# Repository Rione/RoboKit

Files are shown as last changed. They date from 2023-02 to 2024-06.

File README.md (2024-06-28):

# RoboKit 環境構築

<aside>
👉 目標：自分のPCにRoboKit用のプログラムを持ってきて、VSCodeに拡張機能のPlatformIOをinstallする。

</aside>

# 自分のPCにRoboKitのプログラムを持ってくる

↓これを開く

[GitHub - Rione/RoboKit](https://github.com/Rione/RoboKit/tree/master)

## 2つの方法がある

- ファイルをダウンロードする
- ファイル(リポジトリ)をクローンする

## 方法1

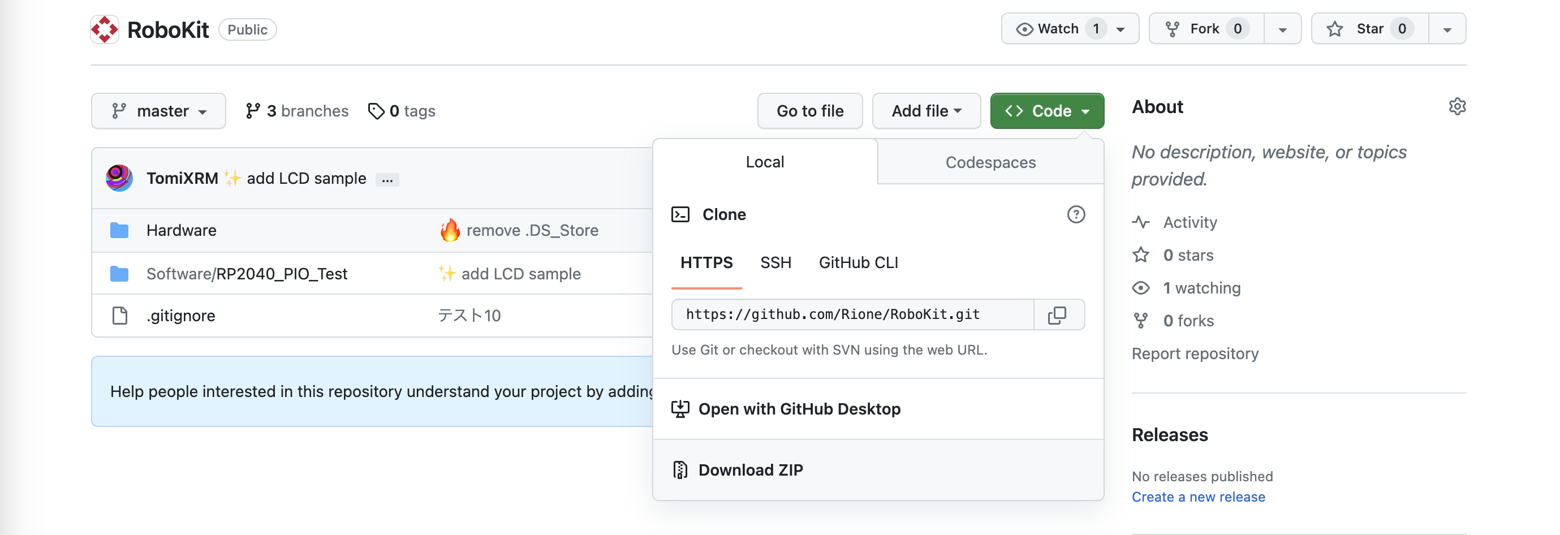
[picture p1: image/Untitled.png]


`<>Code`から、`Download ZIP`でZIPファイルをダウンロード。→ 展開する。

RoboKit-masterというフォルダがDownloadsフォルダに保存されている

## 方法2



今回はDownloadsフォルダにRoboKitのフォルダを複製する
↓一行ずつターミナルで実行

```bash
cd
cd Downloads
git clone https://github.com/Rione/RoboKit.git
```

※ ちなみに…  `git clone (URL)` で既存のリポジトリを自分のPC内に複製できる

RoboKitというフォルダがDownloadsフォルダに保存されている

# VSCodeのインストール

[](https://code.visualstudio.com/)

# VSCodeにPlatform IOをinstallする

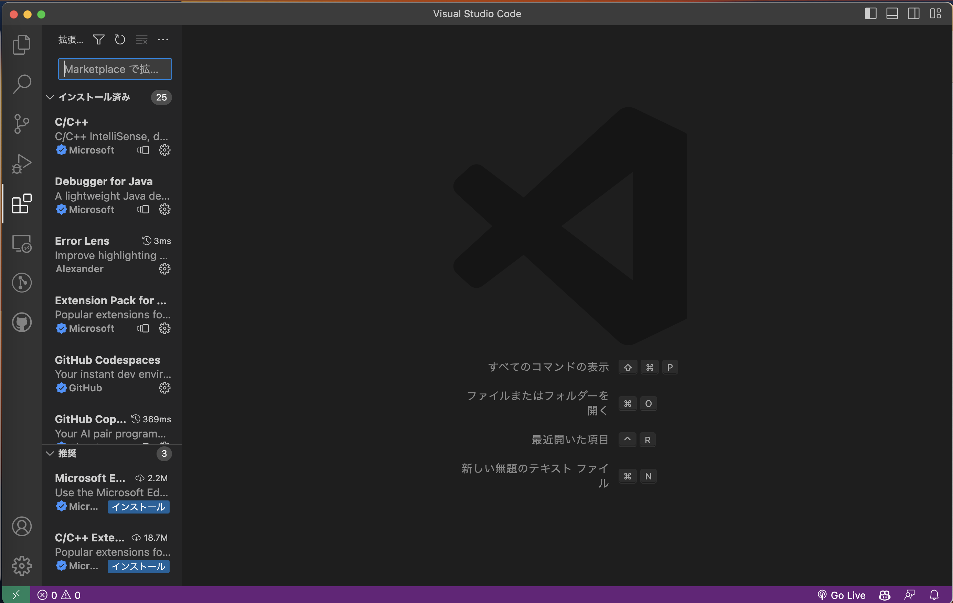
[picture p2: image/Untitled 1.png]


サイドバーの拡張機能（ブロックのようなアイコン）をクリック

上の検索バーにPlatform IOと入力

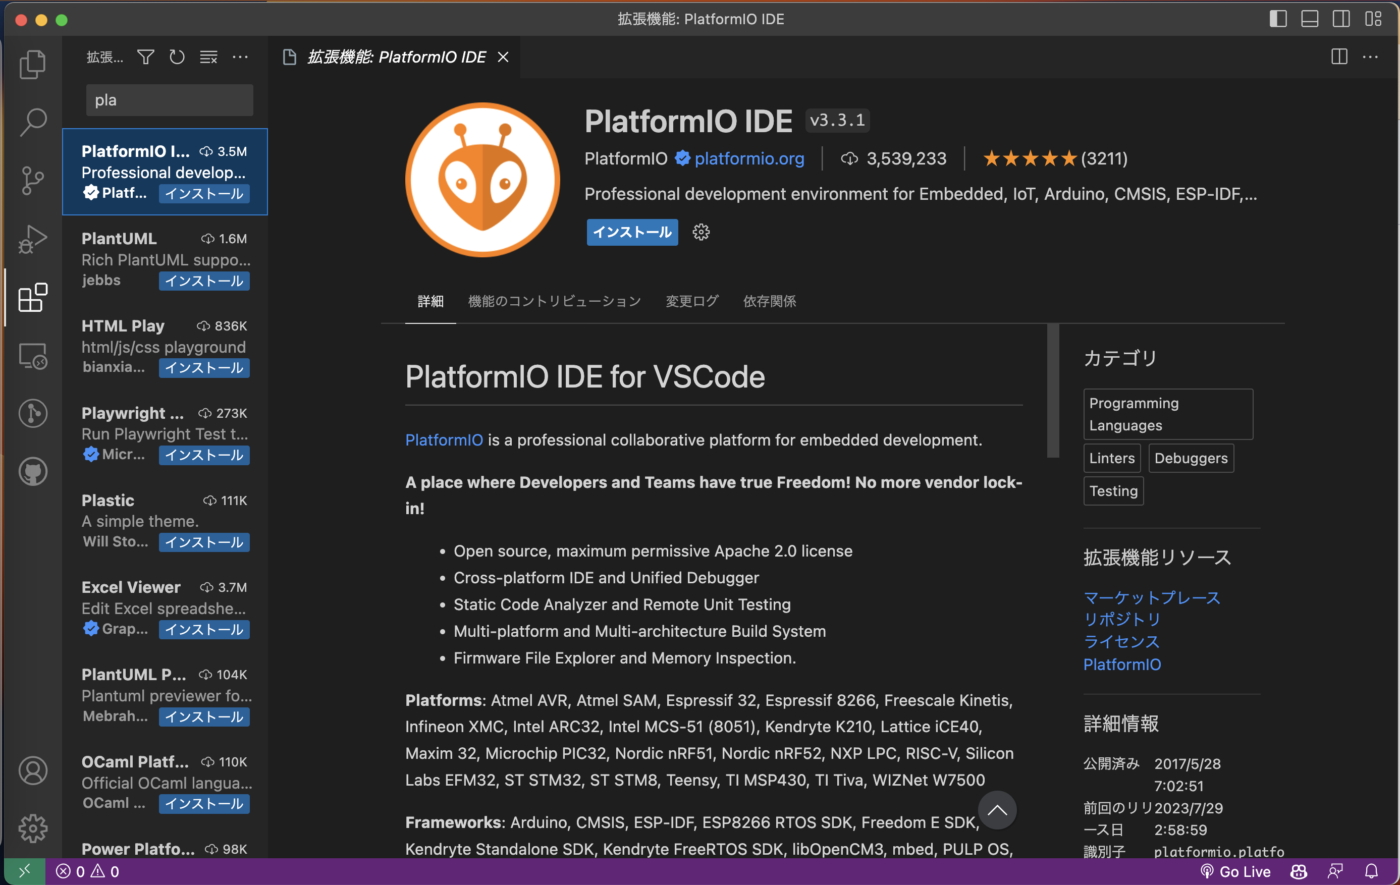
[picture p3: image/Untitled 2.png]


これをinstall(インストールボタンをクリックすることで入ります)

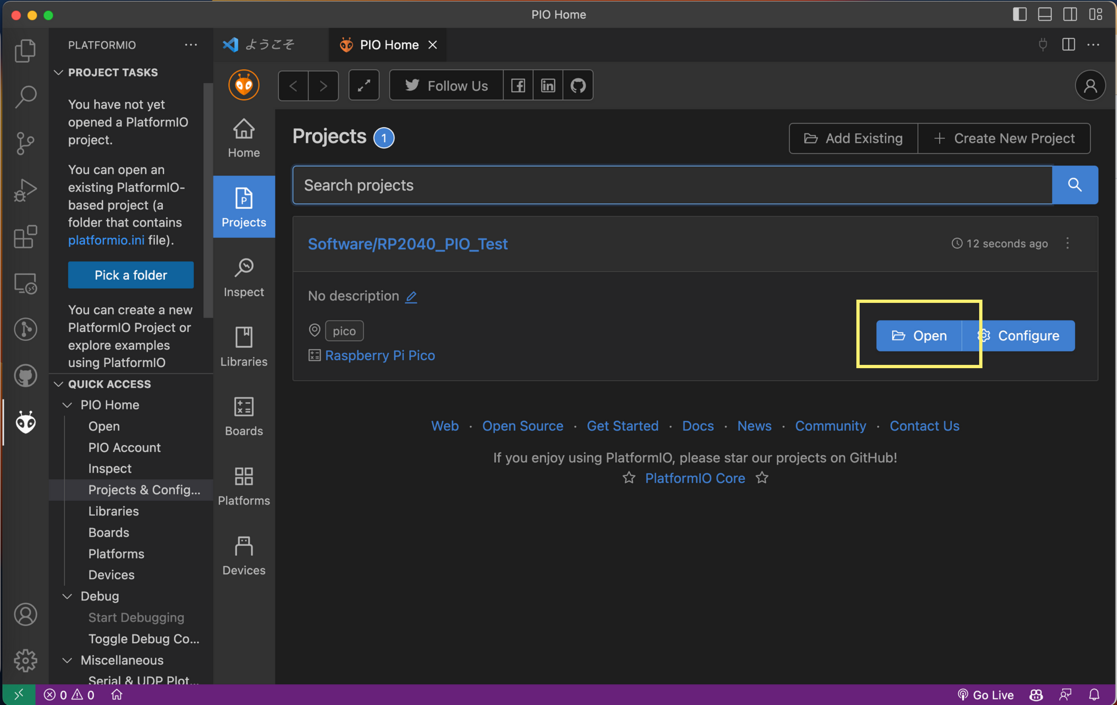
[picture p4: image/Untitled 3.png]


サイドバーからPlatform IOを選択して、Quick Access > PIO Home > Projects & Configure を選択すると、上の画面が出てくる。

画面右側のOpenを押すと、RoboKitのテスト用フォルダが開かれる

---

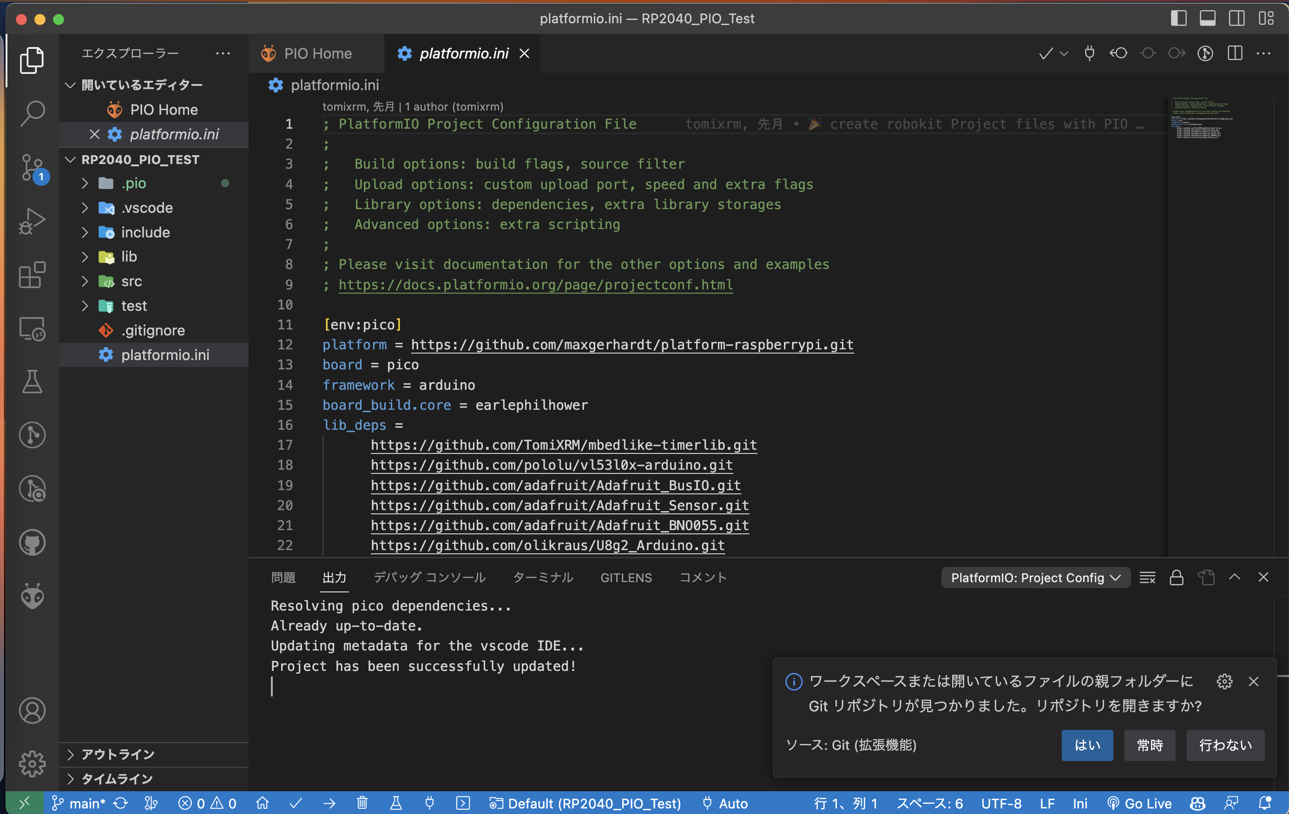
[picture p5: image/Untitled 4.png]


「出力」でいろいろ流れて、最終的に上の画面になったら成功！

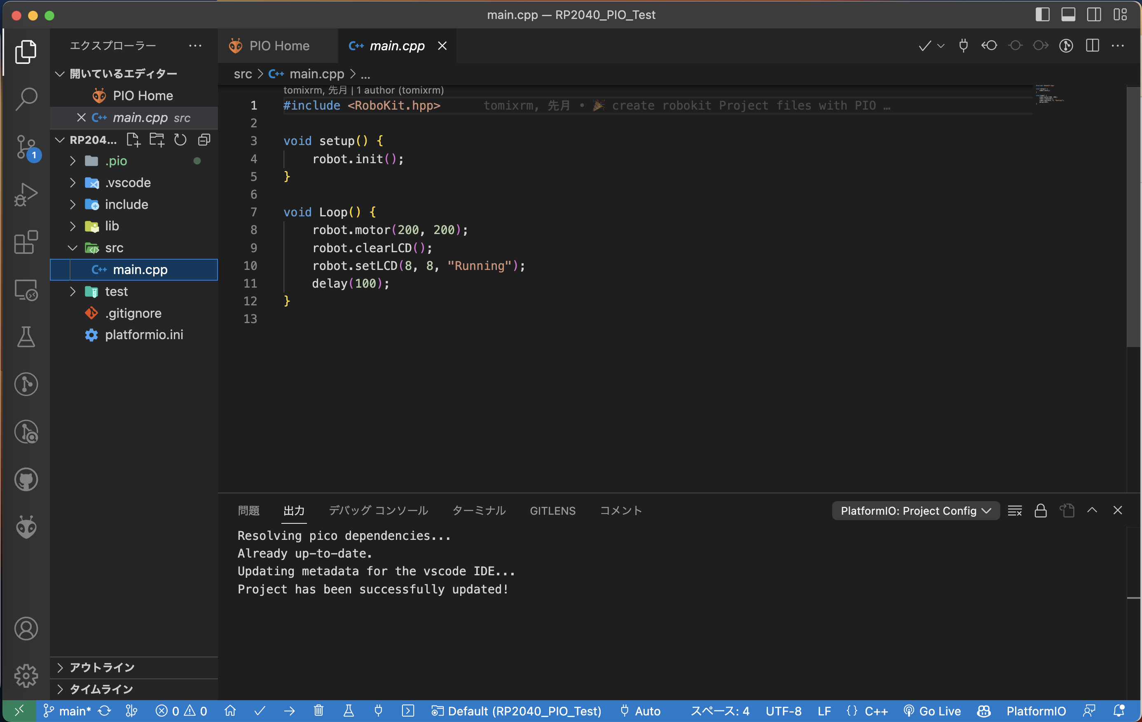
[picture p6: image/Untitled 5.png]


企画で使用するファイルは上画面で表示されている、main.cppだけです。

余力のある人は、実際にビルドができるか確認してもらえると嬉しいです。
下の青いラインに並んでいる、✅を押すとビルド、→を押すと書き込みができます。

以上でPCの事前準備はおしまいですが、分からないことがあれば遠慮せずに聞いてください！

---

# Windowsの諸注意

WindowsにGitが入っている必要があります．Gitのインストールをしてください．(自分で調べてください)

### Gitが入っているかの確認

ターミナルで次のコマンドを打ってみてください．

```
git help
```

と打って反応があればGitが入っている証拠です．

- ターミナルで期待される反応はこんな感じです．
    
    ```
    git help
    usage: git [--version] [--help] [-C <path>] [-c <name>=<value>]
               [--exec-path[=<path>]] [--html-path] [--man-path] [--info-path]
               [-p | --paginate | -P | --no-pager] [--no-replace-objects] [--bare]
               [--git-dir=<path>] [--work-tree=<path>] [--namespace=<name>]
               [--super-prefix=<path>] [--config-env=<name>=<envvar>]
               <command> [<args>]
    
    These are common Git commands used in various situations:
    
    start a working area (see also: git help tutorial)
       clone     Clone a repository into a new directory
       init      Create an empty Git repository or reinitialize an existing one
    
    work on the current change (see also: git he
    ```

### RoboKitのファイルの初期化時にエラーが出る(longpathエラー)

- WindowsのgitはMacと違い，longpath = falseになっているので，trueにしましょう
- WindowsのGitの入っているPCで以下のコマンドを実行してください．

```
git config --system core.longpaths true
```

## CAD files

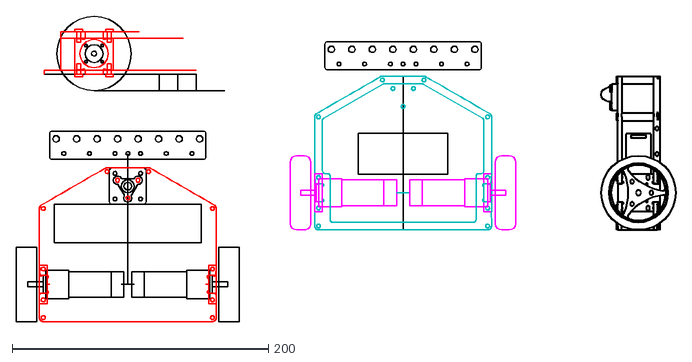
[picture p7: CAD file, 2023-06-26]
Hardware/mechanical_design/robot..dxf
514.6 x 238.2

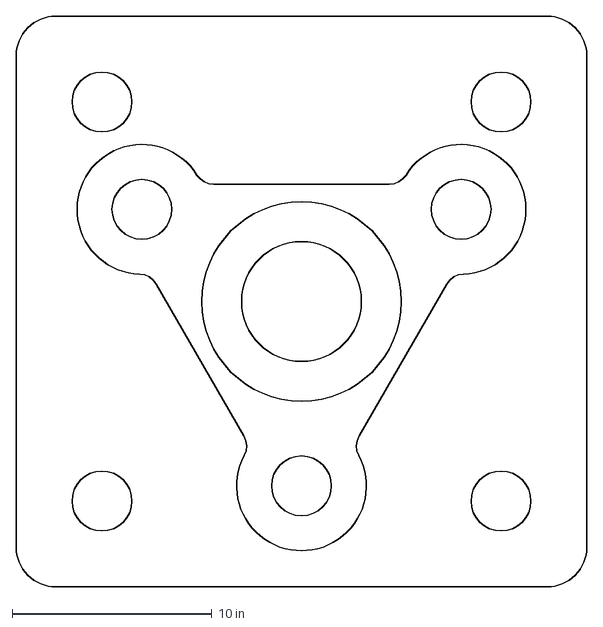
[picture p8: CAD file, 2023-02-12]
Hardware/mechanical_design/キャスタ.dxf
28.6 x 28.6 in

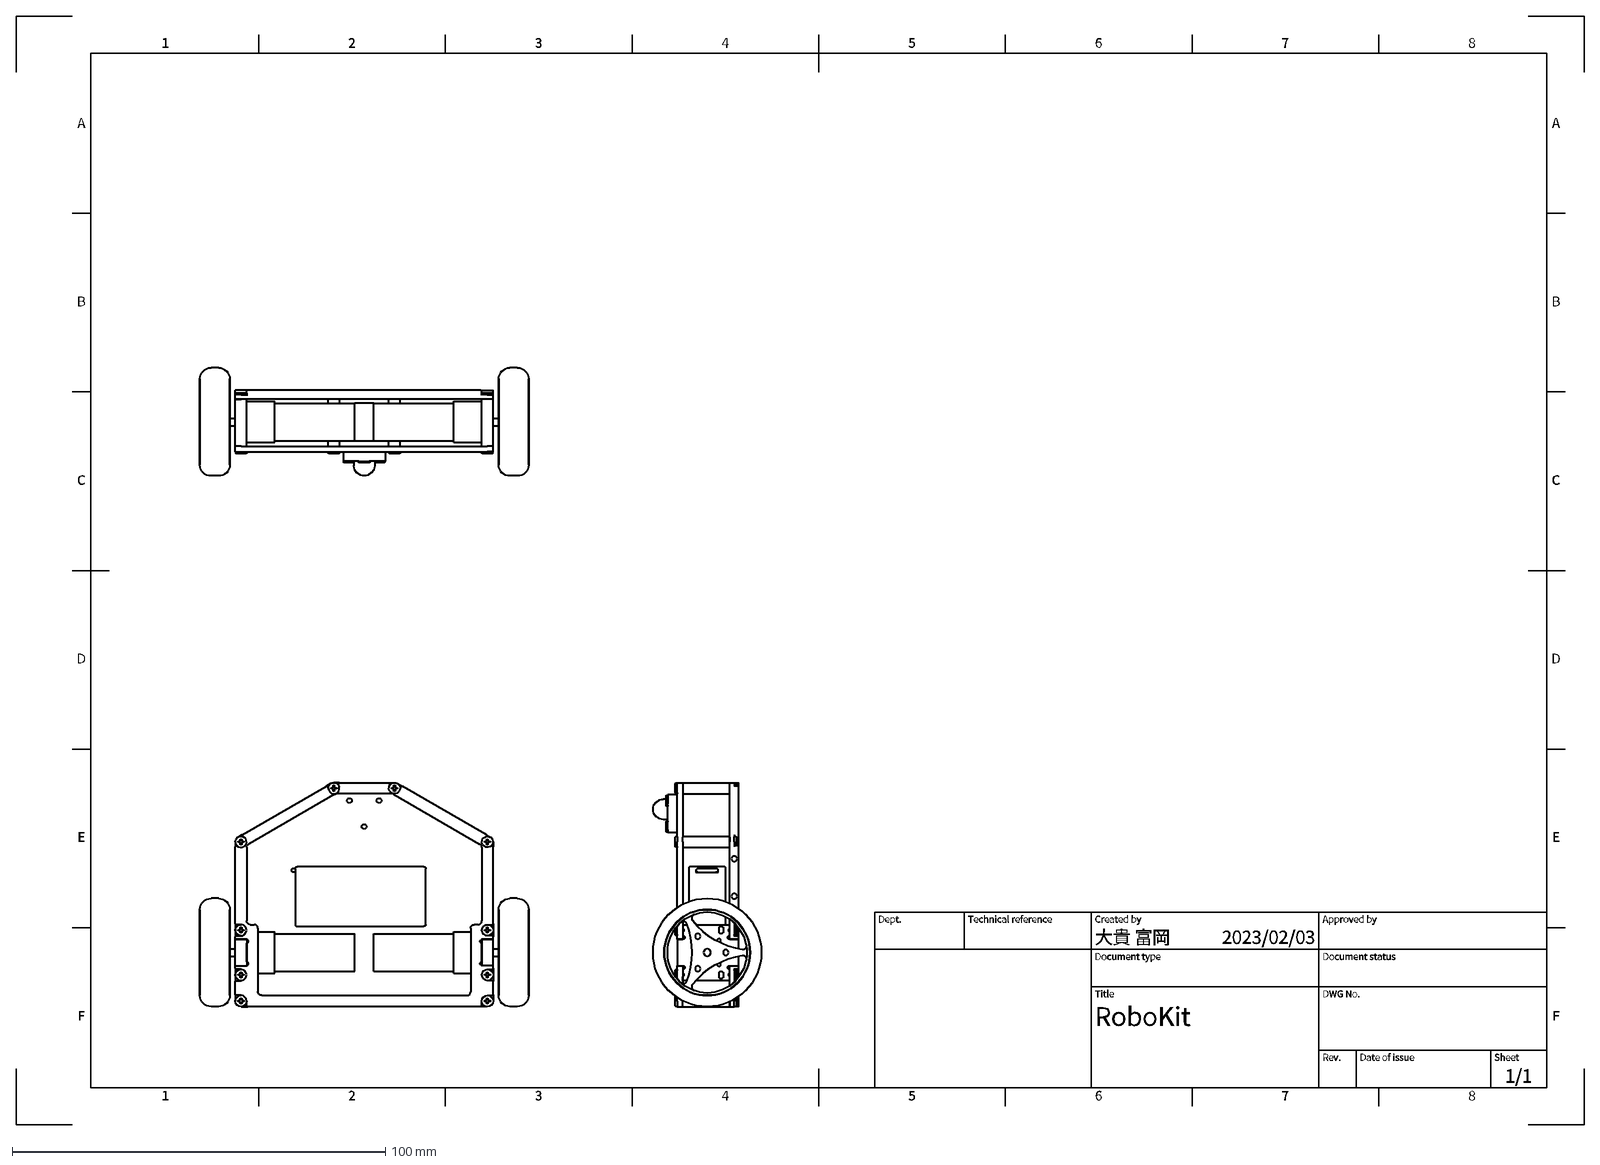
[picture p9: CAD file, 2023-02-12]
Hardware/mechanical_design/無題.dxf
1
A
2
3
4
5
6
7
8
B
C
D
E
F
2023/02/03
1/1
RoboKit
大貴 富岡
Dept.
Technical reference
Created by
Approved by
Document type
Document status
Title
DWG No.
Rev.
Date of issue
Sheet

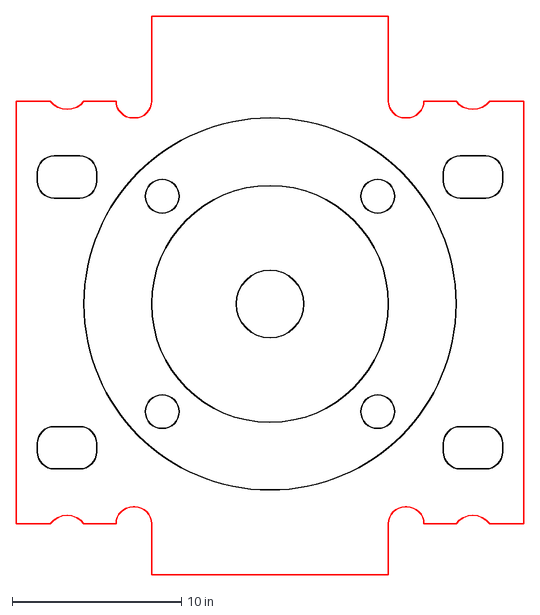
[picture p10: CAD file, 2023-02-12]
Hardware/mechanical_design/mount.dxf
30.0 x 33.0 in

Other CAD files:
Hardware/mechanical_design/motor.dxf
Hardware/mechanical_design/無題.dwg

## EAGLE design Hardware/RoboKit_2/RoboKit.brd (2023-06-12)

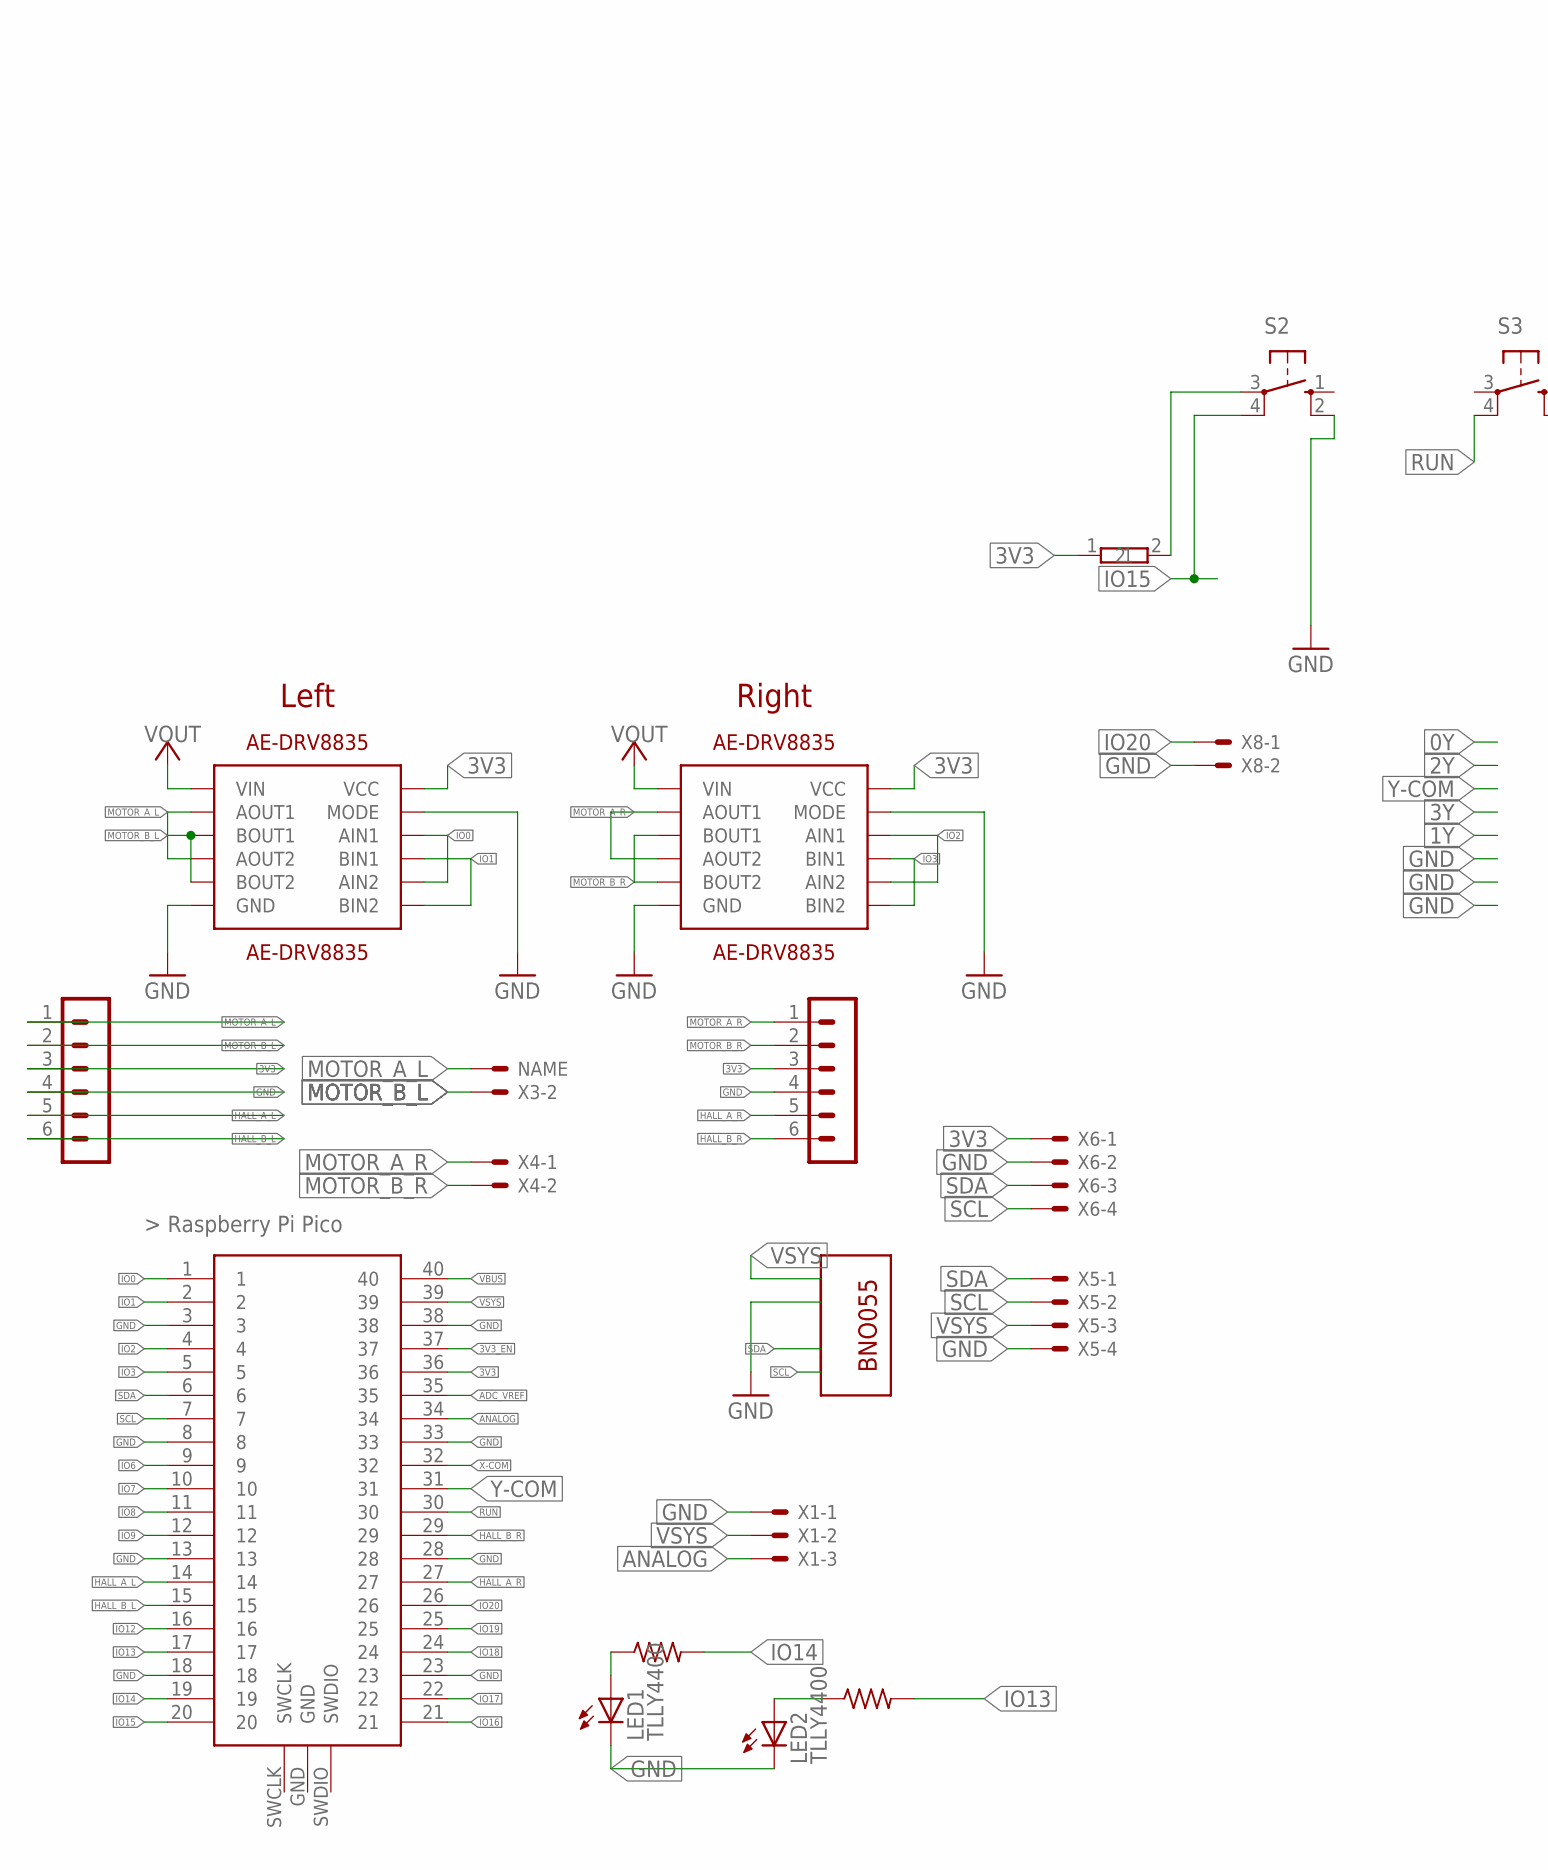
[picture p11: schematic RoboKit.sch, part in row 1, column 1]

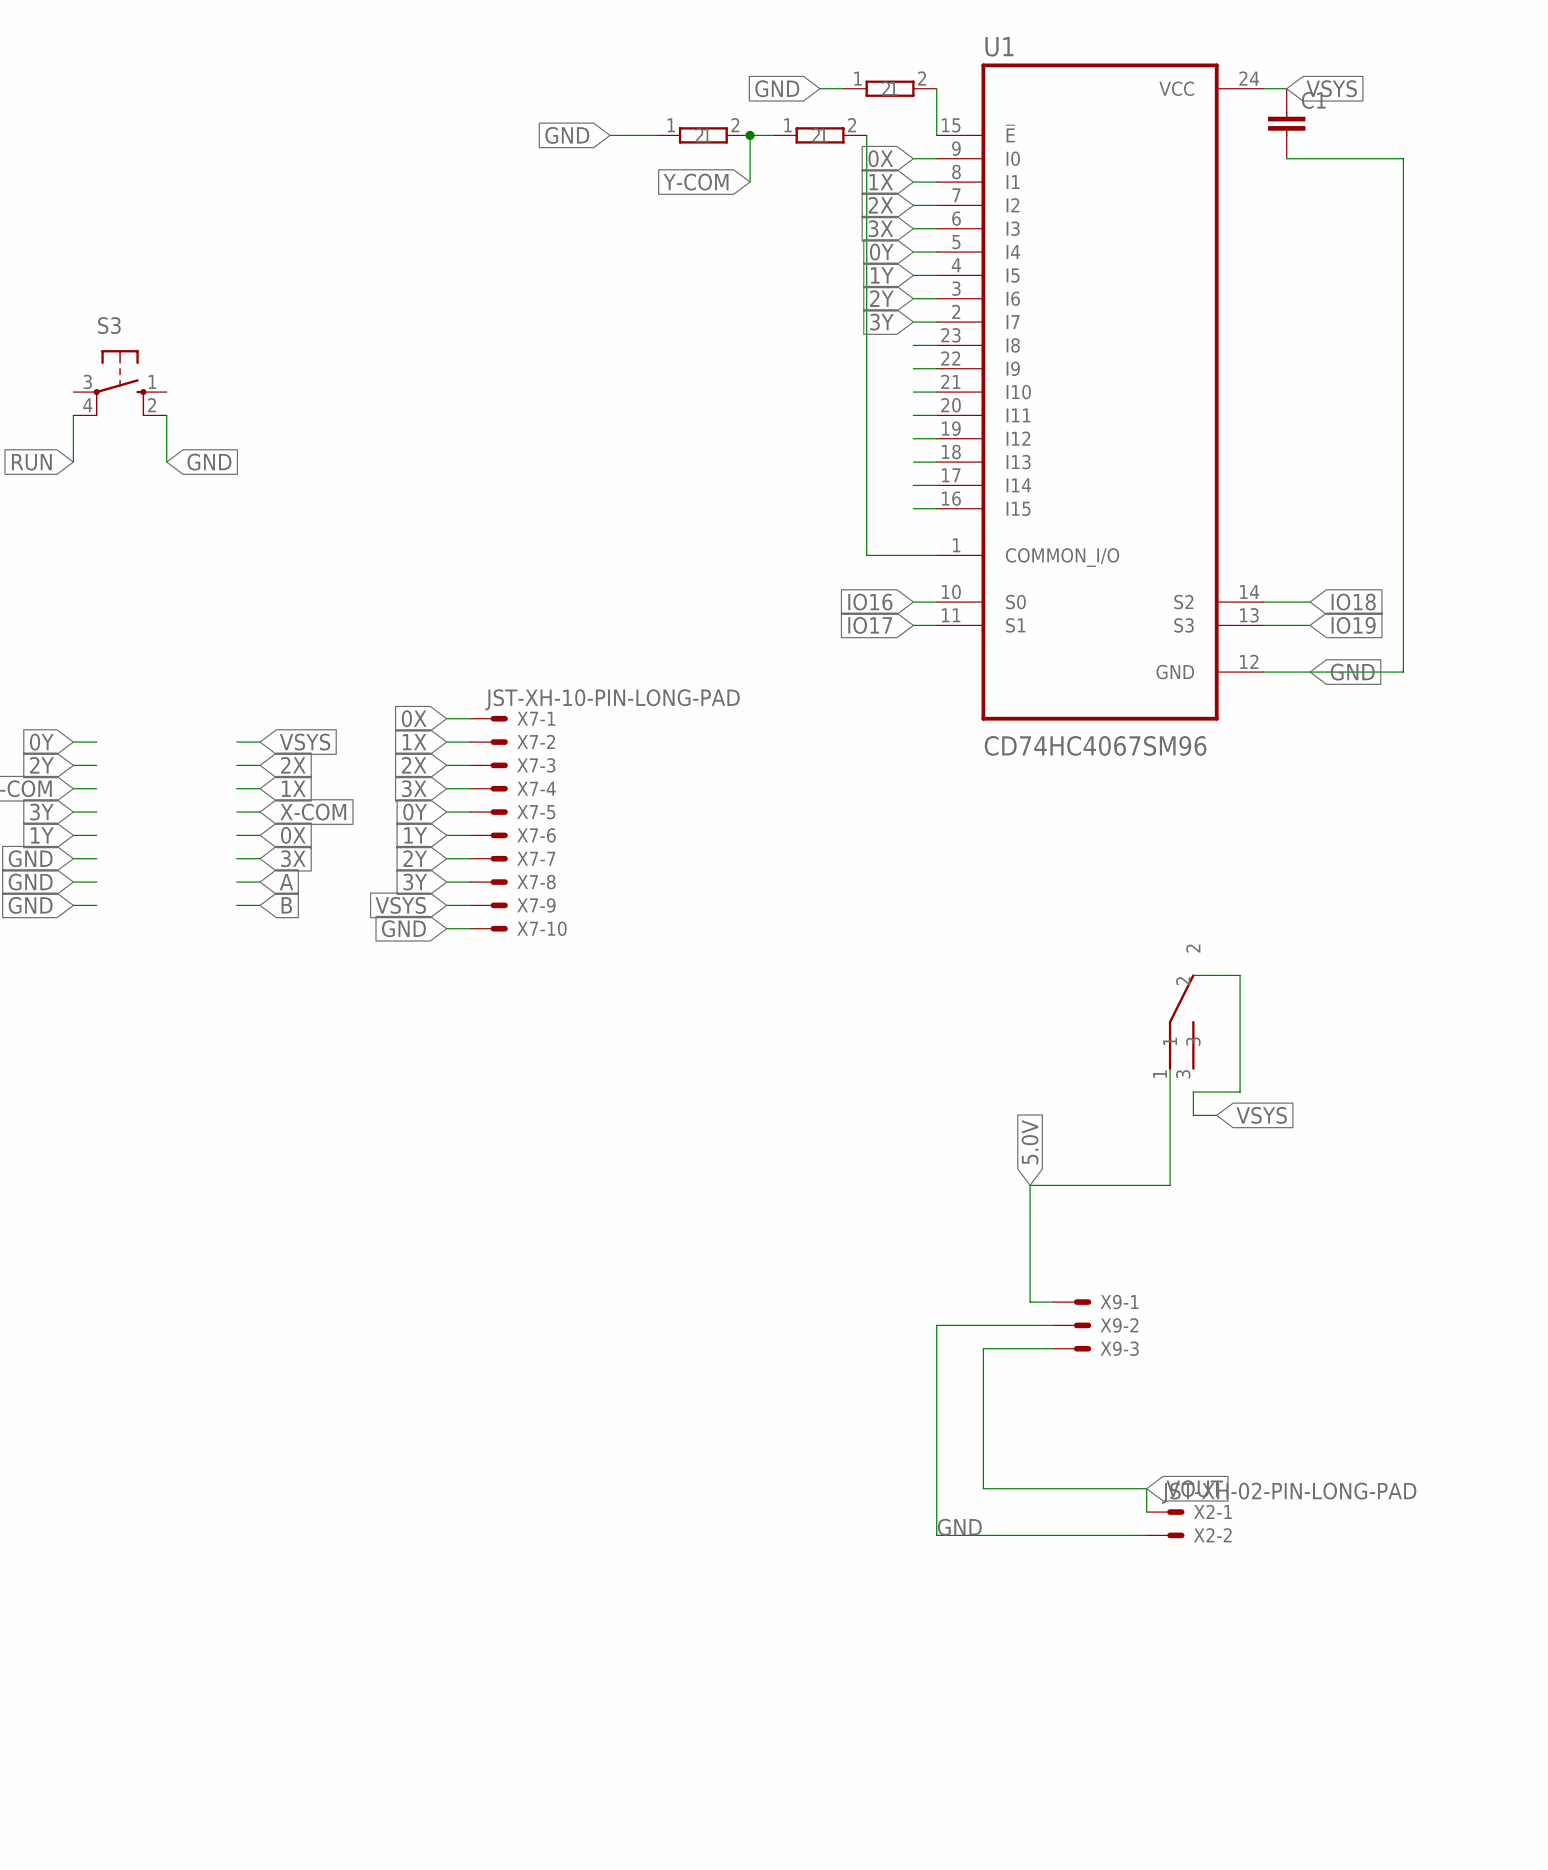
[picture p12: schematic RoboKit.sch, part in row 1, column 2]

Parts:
C1: C-EU025-024X044; C025-024X044
CONNECTOR1, CONNECTOR4, CONNECTOR5, CONNECTOR6: RESISTER; RESISTER_SOCKET
LED1, LED2: TLLY4400; LED3MM
P1, P2: B6B-PH-K
R2, R3: R-US_R0603; R0603
S2: 40-XX; B3F-40XX
S3: 10-XX; B3F-10XX
U1: CD74HC4067SM96; SOP65P780X200-24N
U$1: RASPBERRY-PI-PICO_TH; FT_RASPBERRY-PI-PICO_TH
U$2, U$3: AE-DRV8835
U$4: AE-BNO055-BO
U$8: SW
X1, X9: JST-XH-03-PIN-LONG-PAD; JST-XH-03-PACKAGE-LONG-PAD
X2, X3, X4, X8: JST-XH-02-PIN-LONG-PAD; JST-XH-02-PACKAGE-LONG-PAD
X5, X6: JST-XH-04-PIN-LONG-PAD; JST-XH-04-PACKAGE-LONG-PAD
X7: JST-XH-10-PIN-LONG-PAD; JST-XH-10-PACKAGE-LONG-PAD

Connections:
0X: U1.9 (I0), X7.1
0Y: U1.5 (I4), X7.5
1X: U1.8 (I1), X7.2
1Y: U1.4 (I5), X7.6
2X: U1.7 (I2), X7.3
2Y: U1.3 (I6), X7.7
3V3: CONNECTOR1.1, P1.3, P2.3, U$1.36, U$2.VCC, U$3.VCC, X6.1
3V3_EN: U$1.37
3X: U1.6 (I3), X7.4
3Y: U1.2 (I7), X7.8
5.0V: U$8.1, X9.1
ADC_VREF: U$1.35
ANALOG: U$1.34, X1.3
GND: C1.2, CONNECTOR5.1, CONNECTOR6.1, LED1.K (C), LED2.K (C), P1.4, P2.4, S2.2 (S1), S3.2 (S1), U1.12 (GND), U$1.3, U$1.8, U$1.13, U$1.18, U$1.23, U$1.28, U$1.33, U$1.38, U$2.GND, U$2.MODE, U$3.GND, U$3.MODE, U$4.GND, X1.1, X2.2, X5.4, X6.2, X7.10, X8.2, X9.2
HALL_A_L: P2.5, U$1.14
HALL_A_R: P1.5, U$1.27
HALL_B_L: P2.6, U$1.15
HALL_B_R: P1.6, U$1.29
IO0: U$1.1, U$2.INA1 (AIN1), U$2.INA2 (AIN2)
IO1: U$1.2, U$2.INB1 (BIN1), U$2.INB2 (BIN2)
IO2: U$1.4, U$3.INA1 (AIN1), U$3.INA2 (AIN2)
IO3: U$1.5, U$3.INB1 (BIN1), U$3.INB2 (BIN2)
IO6: U$1.9
IO7: U$1.10
IO8: U$1.11
IO9: U$1.12
IO12: U$1.16
IO13: R3.2, U$1.17
IO14: R2.2, U$1.19
IO15: S2.4 (P1), U$1.20
IO16: U1.10 (S0), U$1.21
IO17: U1.11 (S1), U$1.22
IO18: U1.14 (S2), U$1.24
IO19: U1.13 (S3), U$1.25
IO20: U$1.26, X8.1
MOTOR_A_L: P2.1, U$2.AOUT1, U$2.AOUT2, X3.1
MOTOR_A_R: P1.1, U$3.AOUT1, U$3.AOUT2, X4.1
MOTOR_B_L: P2.2, U$2.BOUT1, U$2.BOUT2, X3.2
MOTOR_B_R: P1.2, U$3.BOUT1, U$3.BOUT2, X4.2
unnamed: LED1.A, R2.1
unnamed: CONNECTOR1.2, S2.3
unnamed: LED2.A, R3.1
unnamed: CONNECTOR6.2, U1.15 (!E)
unnamed: CONNECTOR4.2, U1.1 (COMMON_I/O)
RUN: S3.4 (P1), U$1.30
SCL: U$1.7, U$4.SCL, X5.2, X6.4
SDA: U$1.6, U$4.SDA, X5.1, X6.3
VBUS: U$1.40
VOUT: U$2.VIN, U$3.VIN, X2.1, X9.3
VSYS: C1.1, U1.24 (VCC), U$1.39, U$4.VIN, U$8.2, X1.2, X5.3, X7.9
X-COM: U$1.32
Y-COM: CONNECTOR4.1, CONNECTOR5.2, U$1.31

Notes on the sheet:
Right
Left

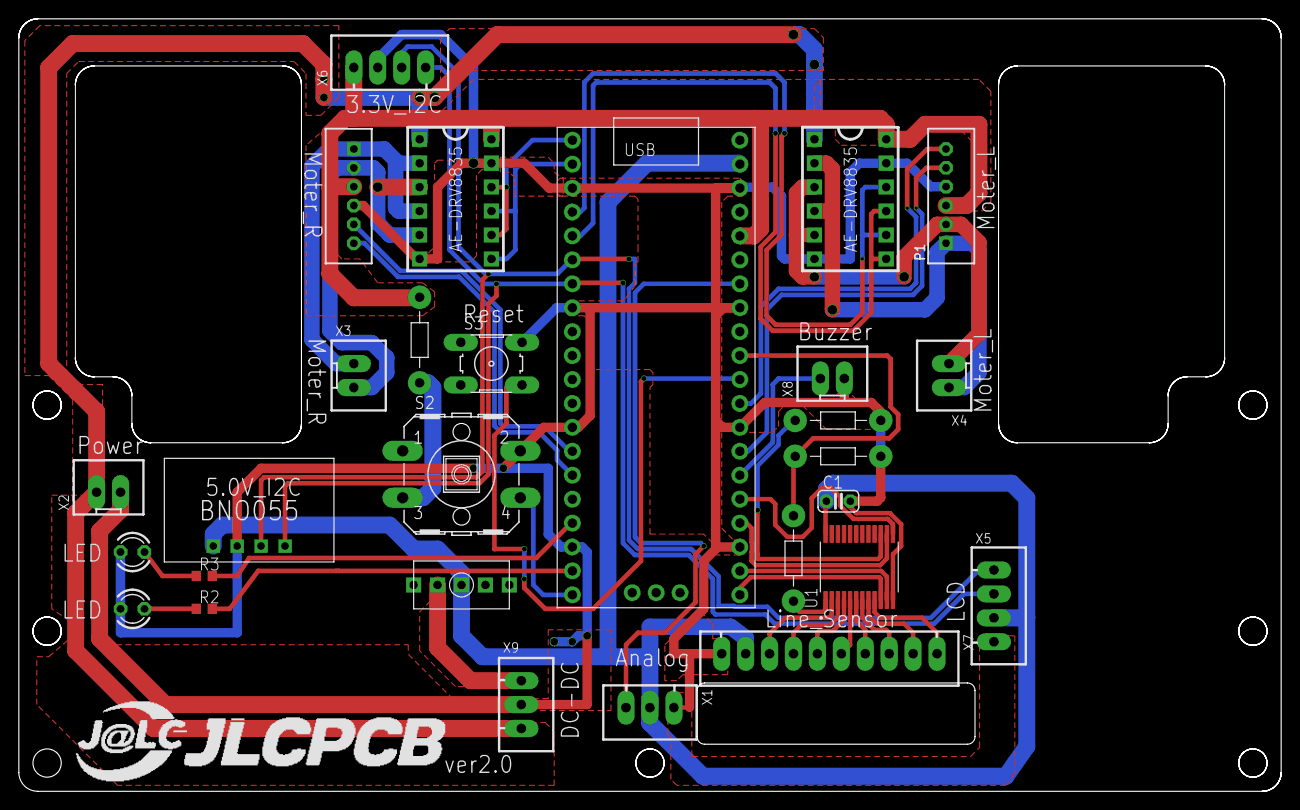
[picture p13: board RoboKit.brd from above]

Board: 2 copper layers, 134.0 x 82.0 mm, 28 parts (0 on the bottom side), 43 nets.

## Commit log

2023-02-03 add cad
    [robot..dxf]
2023-02-12 保護回路を描いた
    [RoboKit.brd, RoboKit.sch, motor.dxf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]
2023-02-28 add I2C
2023-03-10 回路図の完成
    [RoboKit.brd, RoboKit.sch]
2023-03-10 ボードのグランド以外を配置
    [RoboKit.brd, RoboKit.sch]
2023-03-12 線を斜めに配置
    [RoboKit.brd, RoboKit.sch]
2023-03-13 保護回路の配線を設定
    [RoboKit.brd]
2023-03-14 一応完成
    [RoboKit.brd]
2023-03-16 gitignoreを設定
2023-03-16 テスト2回目
    [RoboKit.brd]
2023-03-16 テスト3回目
    [RoboKit.brd]
2023-03-16 テスト_4
    [RoboKit.brd]
2023-03-16 テスト5回目
    [RoboKit.brd]
2023-03-16 テスト_6
    [RoboKit.brd]
2023-03-16 テスト7
    [RoboKit.brd]
2023-03-16 テスト8
    [RoboKit.brd]
2023-03-16 テスト10
    [RoboKit.sch]
2023-03-18 信号線の太さを変更
    [RoboKit.brd, RoboKit.sch]
2023-03-19 ポリゴンの範囲を拡大
    [RoboKit.brd]
2023-03-20 ポリゴンの面積を拡大
    [RoboKit.brd]
2023-03-21 ビアの位置を修正
    [RoboKit.brd]
2023-03-21 Air wireを修正
    [RoboKit.brd]
2023-03-22 モーター部分の太さを修正
    [RoboKit.brd]
2023-03-28 CAMファイルを追加
    [RoboKit.brd, RoboKit.sch]
2023-04-20 ver2.0の作成
    [RoboKit.brd, RoboKit.sch]
2023-04-20 大半のボード配線を変更
2023-04-21 とりあえず完成！
    [RoboKit.brd, RoboKit.sch]
2023-04-21 かんせい
    [RoboKit.brd]
2023-04-21 シルク追加
    [RoboKit.brd]
2023-04-22 マルチプレクサの電源回り付近を修正
    [RoboKit.brd, RoboKit.sch]
2023-04-24 ロゴマークを追加
    [RoboKit.brd]
2023-05-01 5回目課題
    [RoboKit.brd]
2023-06-10 XH10ピンが刺さらない不具合を修正し、アナログ出力の印刷が逆になっていたのを修正し、ver2.0のシルクを追加
    [RoboKit.brd, RoboKit.sch]
2023-06-10 DRC通過
    [RoboKit.brd]
2023-06-12 :warning: Fix position of JLCPCB logo
    [RoboKit.brd, RoboKit.sch]
2023-06-12 ⚠️ Fix position of JLCPCB logo
    # ==== Emojis ====
    # ✨ :sparkles: Add new feature
    # ✅ :white_check_mark: Update existing feature (not bug)
    # ⚠️ :warning: Fix bug/error
    # 🔥 :fire: Remove files or features
    # ✏️ :pencil2: Fix typos
    # 📝 :memo: Update documentation
    # ♻️ :recycle: Dependencies update
    # 🐧 :penguin: Improved the Linux
    # 🍎 :apple: Improved the macOS
    # 🔖 :bookmark: Add new library
    # 🎉 :tada: Initial commit
    # ==== Format ====
    # :emoji: Subject
    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
    [RoboKit.brd]
2023-06-26 :pencil2: Make Hardware folder
    #
    # Commit body...
    # ==== Messages ====
    # 新規(ファイル)機能追加: Add
    # 機能修正、既存機能追加（バグではない): Update
    # リファクタリング: Clean
    # ファイル名変更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
    [RoboKit.brd, RoboKit.sch, motor.dxf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]
2023-06-26 :fire: remove backup files
    # ファイル名変更:
    #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
2023-06-26 :tada: create robokit Project files with PIO
    # ファ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
2023-06-26 :sparkles: add mbed Like Simple IO-Wrapper
    # ファイ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
2023-06-26 :sparkles: ラインセンサとモータに関するメソッドの追加
    # リファ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
2023-06-26 :sparkles: Add SwitchObserver
    # ファイル名変更: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
2023-06-26 :sparkles: SWが押されたらLoopが走るように変更
    # リファクタリング: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
2023-06-26 :pencil2: fix gitignore
    # 削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
2023-06-26 :fire: remove .DS_Store
    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
2023-06-26 :sparkles: ラインセンサをまとめて読むメソッドを追加
    # リファク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
2023-06-26 :sparkles: サンプルコードを追加
    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
2023-06-26 :pencil2: Doxygen用コメントを追加
    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
2023-06-26 :sparkles: モータの回転方向を設定するsetMotorCWを追加
    # リファクタ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
2023-06-26 :sparkles: ToF(VL53L0X)の読み取りメソッドを追加
    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
2023-06-26 :sparkles: BNO055でEuler angle(degree)の読み取りメソッドの追加
    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
2023-06-26 :sparkles: ラインセンサの値を表示するメソッドを追加
    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
2023-06-26 :pencil2: fix isWhiteの場所 / printLineからprintLinesに変更
    # リファクタリ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
2023-06-26 :pencil2: printLinesにデフォルト引数を追加
    # リファクタリング: Clean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
2023-06-27 :memo: LED Blink
    # 削除な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
2023-06-27 :memo: Doxygenでドキュメント生成した
    # フ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
2023-06-27 :sparkles: Earlephilhower support on PlatformIO
    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
2023-06-27 :sparkles: スイッチ押したらLoopが走るようになった
    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
2023-06-27 :white_check_mark: Motor Test
    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
2023-06-27 :white_check_mark: Line Sensor Test
    # ファイル名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
2023-06-27 :memo: update doxygen
    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
2023-06-27 :warning: fix PWM max value 1023 to 255
    # ファイル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
2023-06-27 :memo: Fix Motor CW / CCW
    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
2023-06-28 :sparkles: add wait() ,wait_ms()
    # ファイル名変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
2023-06-28 :warning: fix wait macro
    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
2023-06-28 :sparkles: Add OLED LCD with U8g2_Arduino
    add https://github.com/olikraus/U8g2_Arduino library
    # 機能修正、既存機能追加（バグではない):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
2023-06-28 :sparkles: add LCD sample
    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

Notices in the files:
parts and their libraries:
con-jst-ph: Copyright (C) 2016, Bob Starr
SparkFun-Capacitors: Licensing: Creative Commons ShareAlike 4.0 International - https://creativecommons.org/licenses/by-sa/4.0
